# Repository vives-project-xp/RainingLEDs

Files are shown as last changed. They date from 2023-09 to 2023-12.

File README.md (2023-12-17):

# RainingLEDs
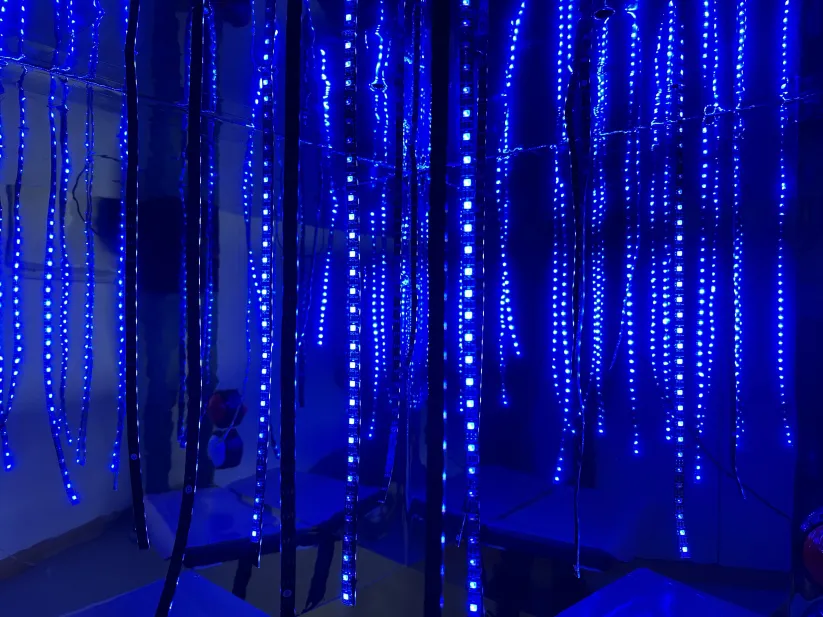
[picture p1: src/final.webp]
The box

<h1 id="What">What?</h1>
    <p>The RainingLEDs project is a project that contains a cool and unique photo location. It's made for all ages, but more focussed on influencers and social media users. Our project consists of a box with mirror foil and 17 LEDstrips, creating an infinite rain illusion. Important to know is that this project is a proof of concept that can help making a bigger version that has yet to be made (see chapter 'Project Expansion'). 
</p>
<h1 id="how">How does it work?</h1>
    <p>The 17 LEDstrips are controlled by an ESP32-C3 microcontroller. That sends signals to the strips to recreate a handful of patterns. At the side of the box the visitors can push on 2 different buttons which put the LEDs in different modes.</p>

<H1>Hardware</H1>
    The "hardware" of the project is described in this chapter.
<h2 id="require">Hardware Requirements</h2>
    <ul>
        <li>+/- 10 meters of sk6812 rgwb LEDstrips</li>
        <li>3 wooden mbf plates making a cube from 70 X 70 X 71.8 cm</li>
        <li>Mirror foil for each side</li>
        <li>ESP32-C3-DevKitM-1 microcontroller</li>
        <li>2 buttons</li>
    </ul>
</ul>
<h2>Box</h2>
    To build the box, we used MBF plates. These are strong wooden plates that can easily be drilled into. The inside of the box has the dimension 70cm x 70cm x 70cm. This is the space where someone can stand in when they want to take a picture. On the inside, we used mirror foil to create the illusion of a bigger number of LEDs. The buttons are placed at the bottom side for easy access when taking a picture. 

<h2>LEDstrips</h2>
    In the current project, we use 17 LEDstrips which are each +/- 50 cm. This is a good length for the current height of the box (70 cm), as such we didn't need an extra 5m led strip just to use 20% of it. To know if using 17 led strips works, we first tested it by using 2 data pins to control all the LEDstrips:
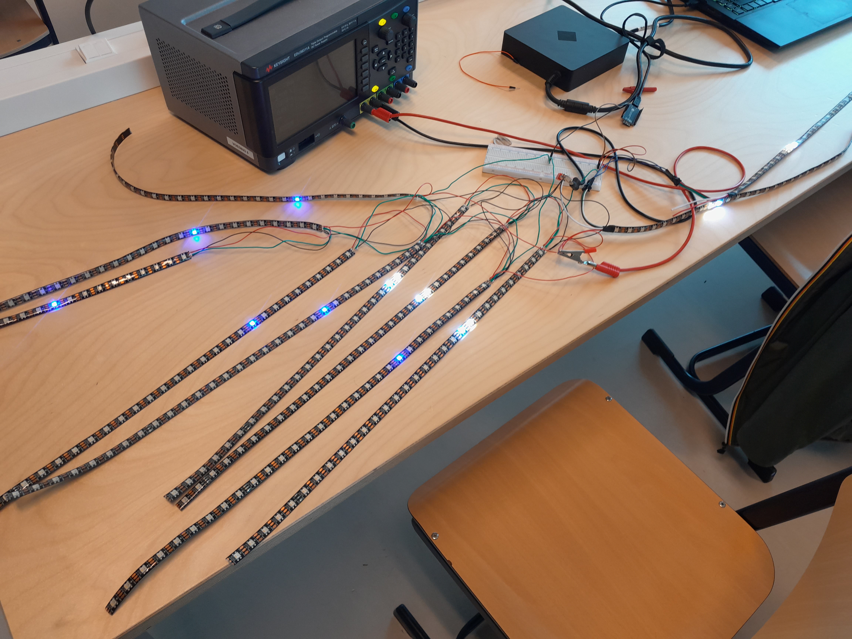
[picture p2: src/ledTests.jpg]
LED tests
    
    Since this worked, we installed the LEDs in the box and connected everything together on top. Because of the drilled holes in the top plate, installing the LEDstrips was easy. We used a breadboard to make all the connections with the esp32. This way, we could easily change the wiring if needed. Here are some things that can be improved about the lighting (additional info can be found in the 'Project Expansion' chapter):
<ul>
    <li>
        In this project, all LEDstrips hang on their own. This means that the side where LEDs are, are faced to the public or to the mirrors on the inside. They are never facing both. This is not a big problem but interferes with the illusion of the mirrors. This problem could be solved by putting 2 LEDstrips back to back, instead of hanging them alone.
    </li>
    <li>
        Each LEDstrip is connected directly to the ESP32. This means that there is maximum 3.3V on the data pin when sending a high signal. This can be the reason why the LEDs are not always working as intended. This can be solved by using a transistor or a MOSFET to amplify the signal. 
    </li>
</ul>
<h1>Software</h1>
    <h2>Adafruit_NeoPixel library</H2>
        This project was coded in C++ using the Adafruit_NeoPixel library. Follow the next steps to download the library (in Visual Studio Code).
        First you'll need to download the PlatformIO extension. Go to 'PIO Home' and select 'New Project'. Use the following settings in the next window:
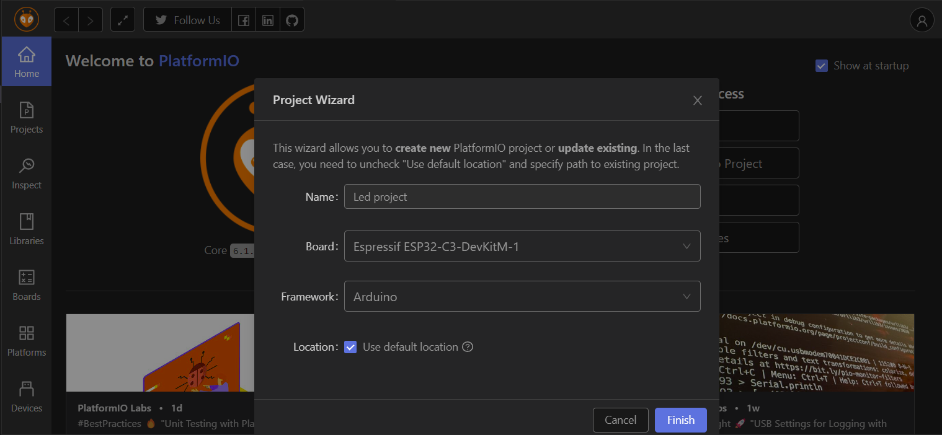
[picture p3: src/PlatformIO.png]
Platform IO screenshot
        
        Now we just need to import the Adafruit_NeoPixel.h library into our project (included inside the main.cpp file). You can simply do this by searching the Adafruit Neopixel library in the Libraries menu (at the left side in PIO Home). You should now be able to use the code on the ESP32 by building it and uploading it!
    <h2>main.cpp</h2>
        In the main program file for the project, there are 3 crucial parts:
        <ul>
            <li>
                <h3>Buttons</h3>
                The buttons are programmed to be triggered on the positive flank. This means that when the button is going from a low state to a high state, the program will interpret that as a button press. This means that nothing will happen when someone releases the button or holds it. To reduce the dander, there is a delay programmed to filter only one positive flank.
            </li>
            <li>
                <h3>Cycle</h3>
                The cycle is the part of the program that is responsible for changing the pattern. When a button is pressed, the cycle will change to the next pattern. This is done by using an array which includes all patterns where the index, which is used to filter the correct data, is increased or decreased. When the index is bigger than the array, the index will be set to 0. When the index is smaller than 0, the index will be set to the last index of the array.
            </li>
            <li>
                <h3>Sending data</h3>
                To send the data to the LEDstrips, the correct data has to be filtered. This is done by using a series of if-statements which checks the data in the array from above. when the correct data is found, the data will be sent to the ledstrips. This is done by using the Adafruit_NeoPixel library. This library has a function called 'show()' which will send the data to the LEDstrips. Since there are 4 data pins, the sent data looks like this:
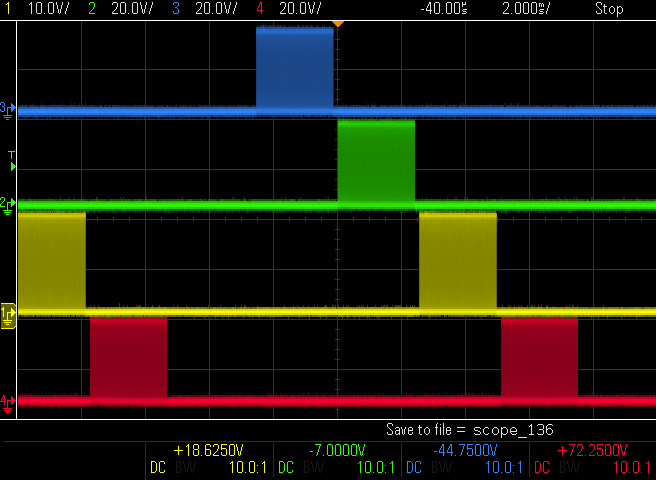
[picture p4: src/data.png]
data
                
            </li>
        </ul>
    <h2>Effects</h2>
    There are 7 different effects that can be cycled through:
    <ul>
    <li><b>Rain:</b></li> The rain effect shows rain falls from 4 LEDs in a blue color. Each datapin has a delay so the drops are falling irregular.
    <li><b>Wave fade:</b></li> The wave fade effect shows a blue wave in the LEDs.
    <li><b>Blinking star light:</b></li> This effect simulates starlight that go on and off in a white color.
    <li><b>Sunrise:</b></li> Sunset colors are slowly waving on the LEDstrips.
    <li><b>Ripple:</b></li> The LEDs are jumping up and down.
    <li><b>Fire:</b></li> A red/orange color is showed, it slightly changes which makes it looks like fire.
    <li><b>Breathing:</b></li> The LEDs are slowly changing from color in a pace that looks like breathing.
    </ul>
    <h2>MQTT</h2>
    The project also has an MQTT interaction with Project Master:  <br></br>
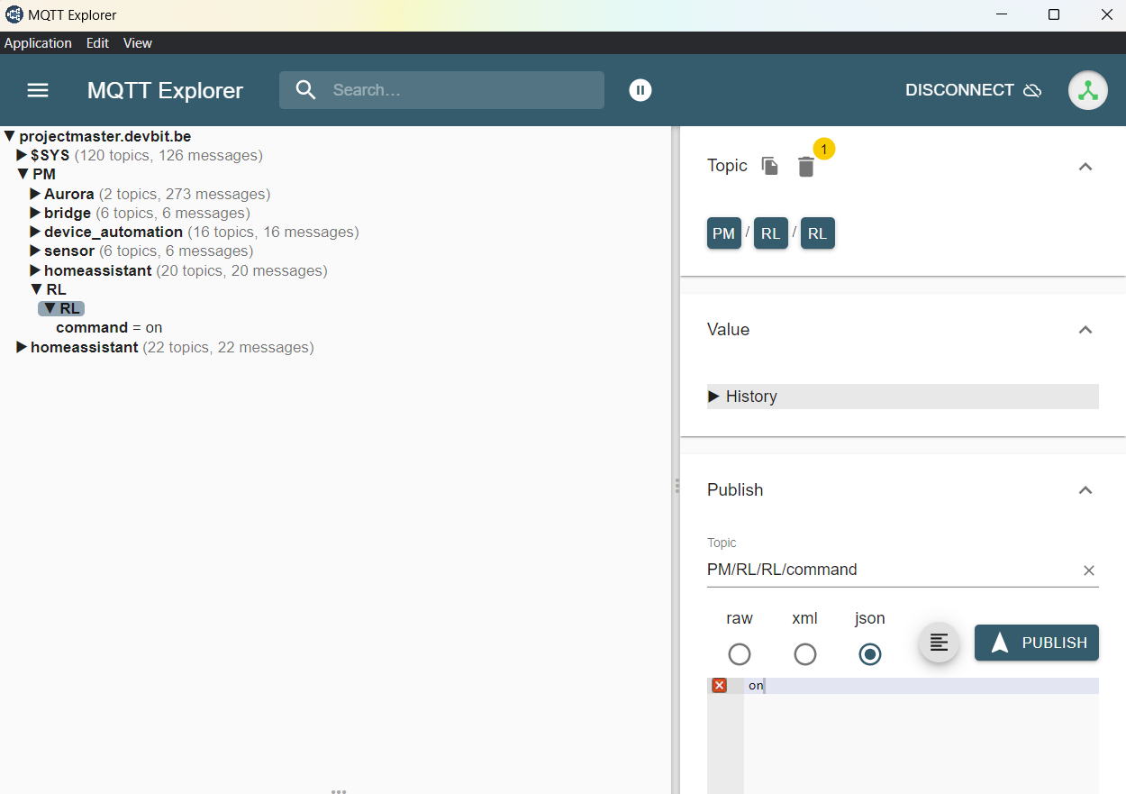
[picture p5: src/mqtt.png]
mqtt explorer
     <br></br>
    There are 4 topic that can be sent to the MQTT broker:
    <ul>
    <li>
    <b>Command:</b> </li> With the command-topic, on and off can be sent to the ESP. When sending 'ON', all LEDstrips will show the first effect. When sending 'OFF', all LEDs will go out.
    <li><b>Rgbw:</b></li> The rgbw-topic needs 4 values and will show that specific color on all LEDstrips.
    <li><b>Brightness</b></li> With the brightness command, the brightness -what a surprise- from the current effect (or color sent by MQTT) will be adjusted.
    <li><b>Effect</b></li> The effect topic shows the selected effect from 7 possible effects.
    </ul>
<h1>Project Expansion</h1>
    Because this project is a proof of concept, there was expected from us to make a project that can be expanded. This means that the project can be used as a base for a bigger project. Here are some ideas that can be used to expand it and an elaborated vision of what this could become.
    <h2>Ideas (more details below)</h2>
        <ul>
            <li>double ledstrips</li>
            <li>bigger box</li>
            <li>use of transistors for data transmission</li>
            <li>using real mirrors instead of foil</li>
            <li>bigger microcontroller</li>
            <li>PCB</li>
            <li>...</li>
        </ul>
    <h2>Our vision</h2>
    As you can see up here, there are a lot of things one can do to make this a incredible project expansion. Under here, we will explain the ideas we think are the most important to make this project a success. Here is our vision of what this project could become.
    <h3>Box</h3>
    <ul>
        <li>
            <h3>Dimensions</h3>
            Our box is in fact too small to take a picture of a full person. This makes it easy to replace, but it's also a disadvantage since the effects would be more spectacular on a human-size box. So a bigger box should be one of the primary improvements this project needs. We think it would be a good thing if a whole person could stand between the hanging ledstrips. This means that the box has to be at least 2 meters high. It would also be a good thing if the width of the box is a little bit bigger. This way, the illusion of the mirrors would be better because there could be more ledstrips and there could be place for multiple persons. <br></br>
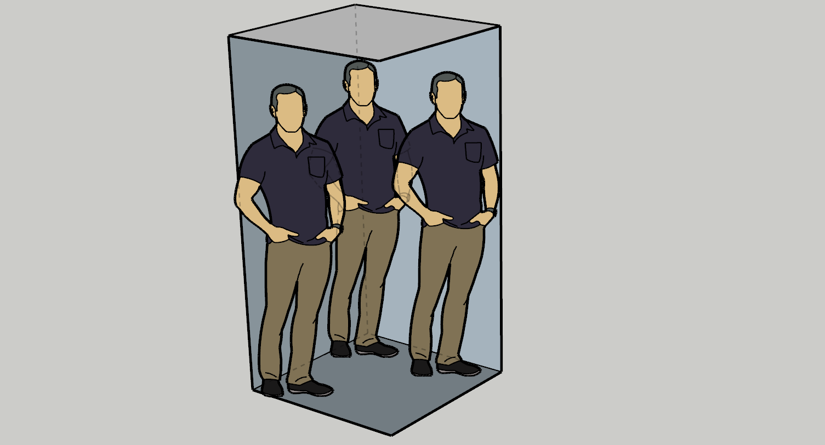
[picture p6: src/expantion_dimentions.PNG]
             <br></br>
            We think the dimensions of 100cm x 100cm x 200cm would be a good size for the box. This way, there is enough space for at least 3 people. If you want to be the project mobile, a possibility of splitting the side panels in 2 using hinges(so you create a 100 X 100 X 100 cm box) could be an option. This way, the box can be transported in a car. 
        </li>
        <li>
            <h3>Mirrors</h3>
            To create the effect that we want, the top and sides of the inside of the box has to be reflective. The best thing to use for this would be -of course- mirrors. In the prototype, we did not use real mirrors because of the expensive price. Another reason we didn't choose real mirrors is the fact that the LEDstrips have to come through the top, this would be very hard to do. Drilling holes in a mirror is a difficult process and will result in a huge money loss if it goes wrong. So for the top part, we would stick to the mirror foil. For the side parts, real mirrors could be considered. While the mirror foil is a cheap and easy way to create the wanted effect, it is not as good as a real mirror. The mirror foil is not as reflective as a real mirror, so the effect is less spectacular.
        </li>
    </ul>
    <h3>LEDstrips</h3>
        When the box becomes bigger, it is normal that the number and length of the ledstrips will increase too. If we want to make a box as described above, a number of 25 ledstrips hanging from above would be perfect in our vision. Since we wanted to double the LEDstrips for the mirror effect (see chapter Hardware), this would come down to 50 ledstrips. When we make each of them 150 cm long, that would mean that there would be 75 meters of ledstrips. This would come down to 277 euro with the type of LEDs we are currently using.
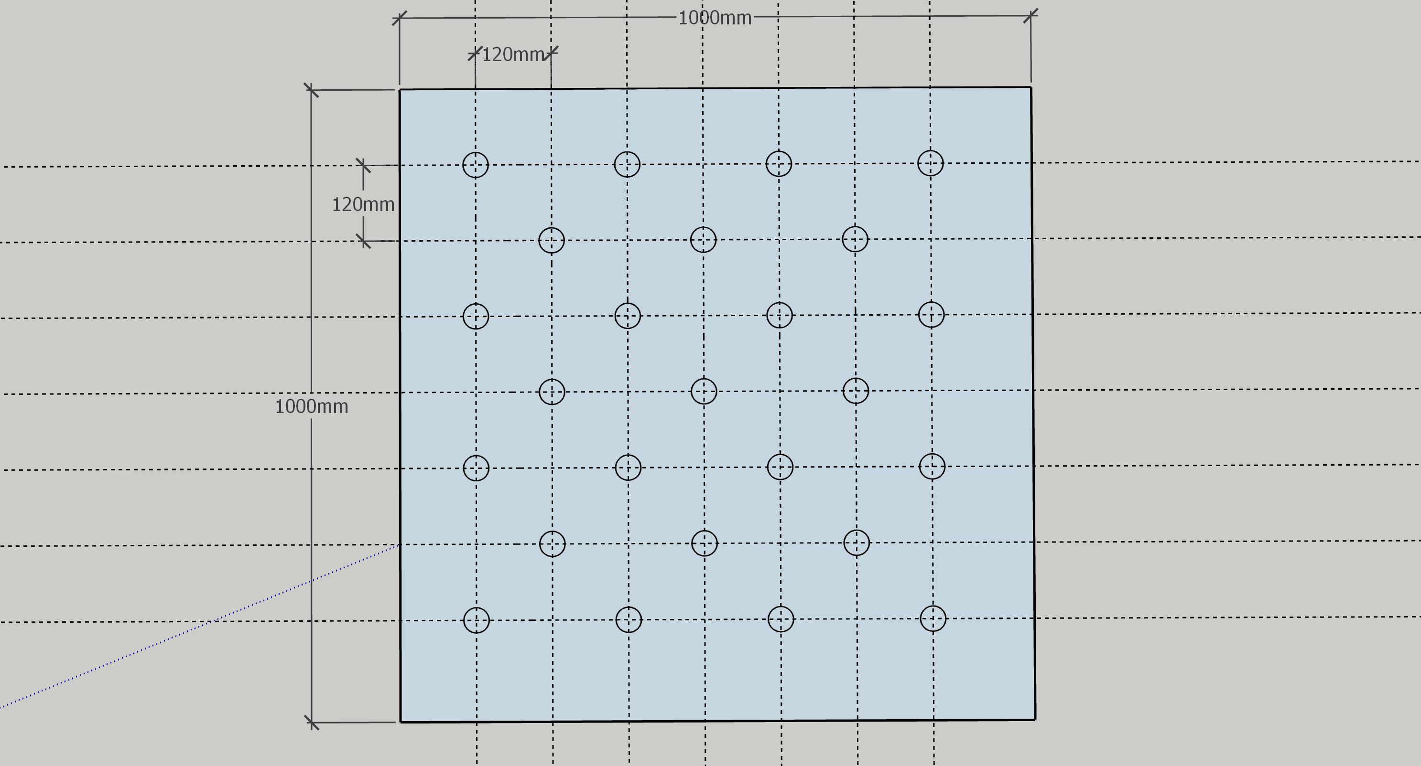
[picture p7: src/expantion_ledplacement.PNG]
        
        This would be a good placement of the LEDstrips. With the staggered placement, the mirrors will reflect as much of the light as possible resulting in a beautiful photo.
    <h3>Electronics</h3>
    <ul>
        <li>
            <h3>Microcontroller</h3>
                The best way to control all ledstrips is when every LEDstrip has its own data pin. This way it is possible for every LEDstrip to do something completely different, which would result in no boundaries for patterns. In the current project, we used an ESP32-C3-DevKitC-02.
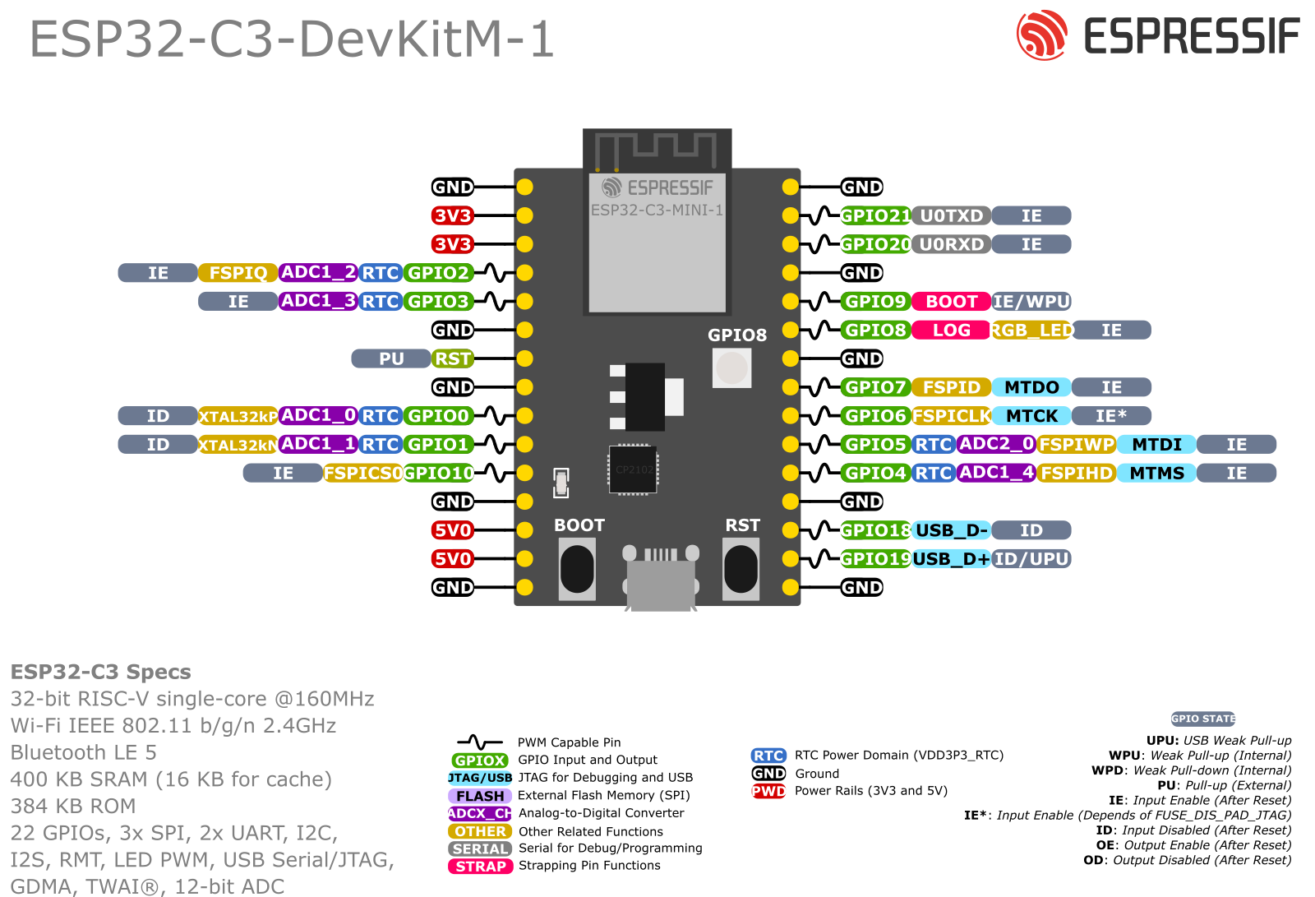
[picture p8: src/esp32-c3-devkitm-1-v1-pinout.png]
esp32-c3-devkitm-1-v1-pinout
                
                This microcontroler has 15 GPIO ports. this is enough for the prototype but not for an expanded version with 25 double LEDstrips. And if we want to keep the two cycle buttons, we would need 27. A good solution would be the ESP32-WROOM-32. This microcontroler has 38 GPIO ports. This would be enough for the expanded version and would give us the possibility to add more buttons or other components.
                <br></br>
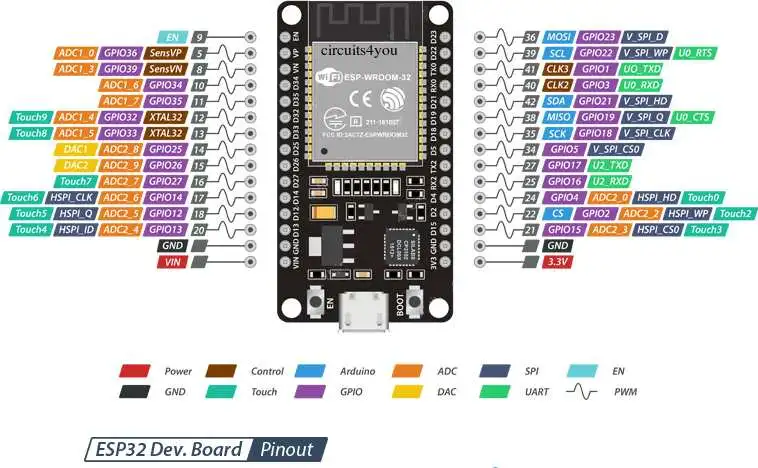
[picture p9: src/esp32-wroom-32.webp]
esp32-wroom
                
        </li>
        <li>
            <h3>Powersupply</h3>
                With 50 ledstrips, the power consumption will of course be a lot higher. This means that the power supply has to be more powerful. When we use 50 ledstrips, the max power consumption would be around 30 Watt. The project would have to be connected to a 5V 6A power supply like the LHA30F-5-SNY: <br></br>
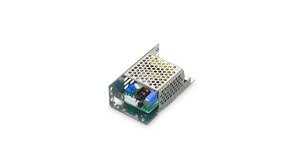
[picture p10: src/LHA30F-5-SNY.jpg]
LHA30F-5-SNY
                
        </li>
        <li>
            <h3>PCB</h3>
        </li>
        To connect all LEDstrips, buttons and other components to the microcontroller, a PCB can be made. In our case, we placed a breadboard on top of the box that connects all components, which makes it easier to see what all our connections and components are when the project will be expanded.
        <li>
            <h3>Data transmission</h3>
        </li>
        To make sure the data transmission from the microcontroller to the LEDstrips goes well, transistors could be used. Since in our case the ESP needs 3.3V and the LEDs 5V, data conflicts could be possible. We sometimes experienced this in the from of LEDs showing colors that weren't meant to be showed or flickering LEDs when adjusting the brightness. But since we could fix most of them in the software, we didn't implement transistors in our case. Another option is to use a logic level converter between the ESP32 and LEDs: 
        <br></br>
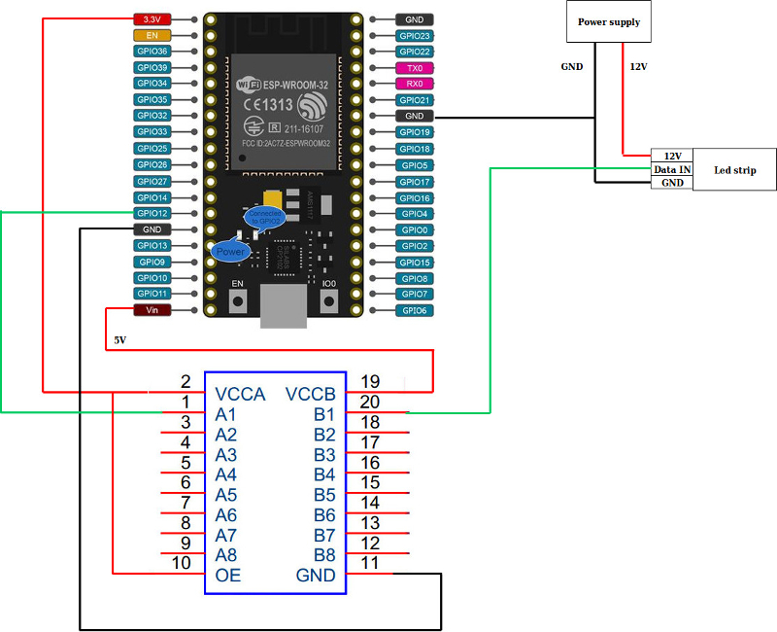
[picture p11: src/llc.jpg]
logic level converter
        
    </ul>

<h1 id="troubleshooting">Troubleshooting & problems</h1>
<h2>LEDstrips</h2>
We had to re-solder a few LEDstrips because the cables were detached while we were putting them in the box. When all the LEDs were in place we noticed that 2 strips stopped functioning and replaced them by 2 smaller strips.
<h2>Coding</h2>
We started coding some simple functions to test the LEDs. After that we extended the LEDstrip to see if it would still work with the ESP32. We encountered a problem with some code examples where the LEDs would not follow the code and would simply show random colours. When the voltage was adapted to the right value, it started working again with a larger LEDstrip. This was all done with one data line, however we wanted to use mutiple data lines to create a more natural flow between the LEDstrips so that there would be some variation. This worked with four data lines but only one pattern at a time. We still had some problems with cycling between dynamic patterns with multiple data lines.
<h2>Power supply</h2>
We began with following the datasheet, so we used a voltage of 3.6 with a school power supply. Because we were working with a voltage of 3.6 we had to consider to limit our brightness so we wouldn't take up a whole lot of wattage. We concluded that the ideal brightness for the LEDs was 60%. This also made sure that the functions worked properly. When we rearranged the wiring of our project, we made it work using our own power supply with 5V.
<h2>Buttons</h2>
The buttons were implemented fairly quickly, but we ran into some problems: they only worked with static functions, not with dynamic patterns and a delay occurred when pushed. We solved the delay problem by adding a debounce system that ensured that only one button press is registered. By working with threads we managed to cycle between dynamic functions.
<h1 id="image">Additional Images</h1>
<h2>Electric schematic</h2> 
First, we wanted to make a LEDcube using 2 data pins and 2 buttons. Because of the 2 data pins, we could send 2 different patterns to the LEDstrips which could make the illusion of falling rain or other dynamic patterns. The initial electric schematic looked like this:
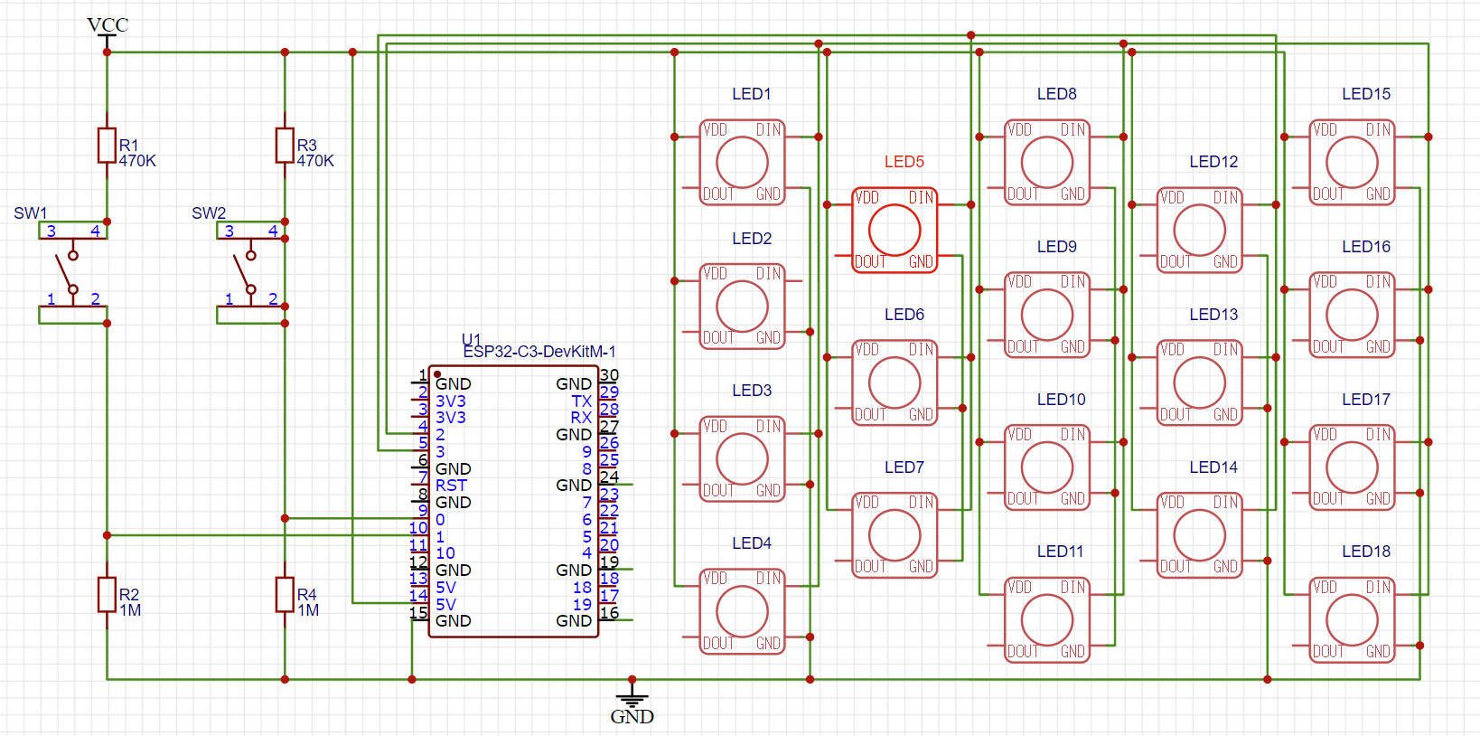
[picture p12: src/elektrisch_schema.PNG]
elektrisch schema

When we slowly progressed on the project, we noticed that the difference between 2 and 4 data pins was not that big. With 4 data pins, there is a grated variety and freedom in the patterns we can create. There are still 2 buttons to cycle between the patterns. The final electrical schematic looks like this:
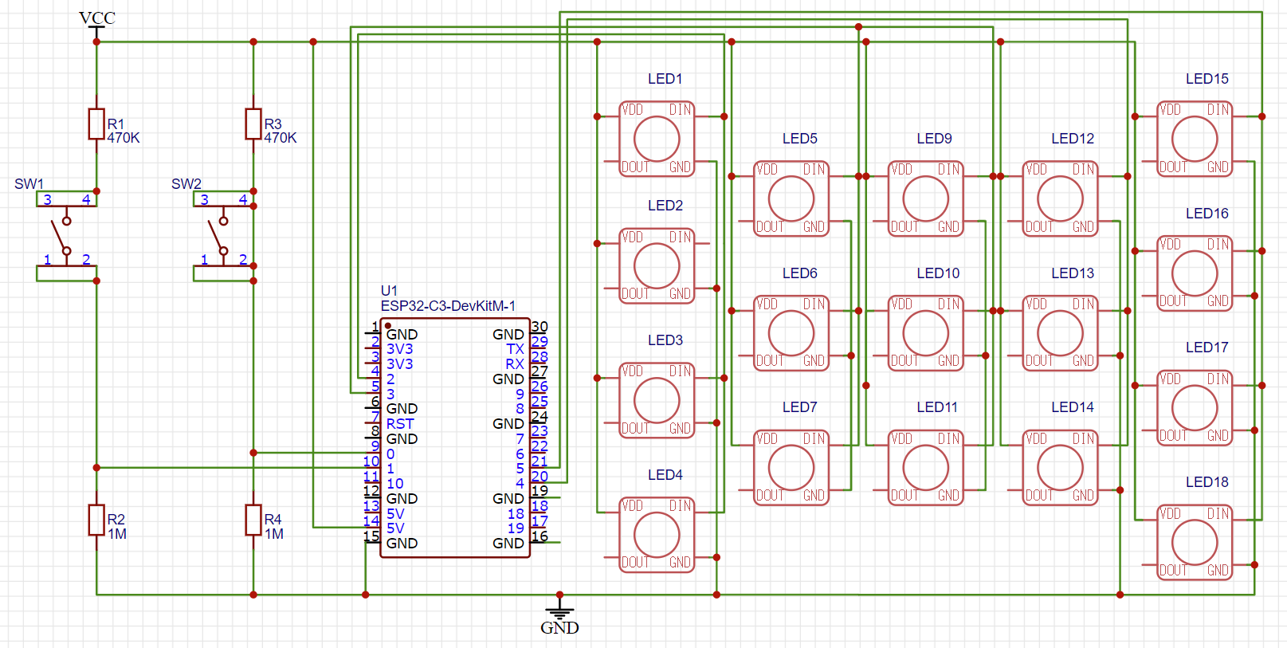
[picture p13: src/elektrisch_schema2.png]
elektrisch schema2

<figcaption>The Electric schematic shows into detail how all the LEDs are connected to the ESP32 microcontroller.</figcaption>
<h2>Projectcanvas</h2>
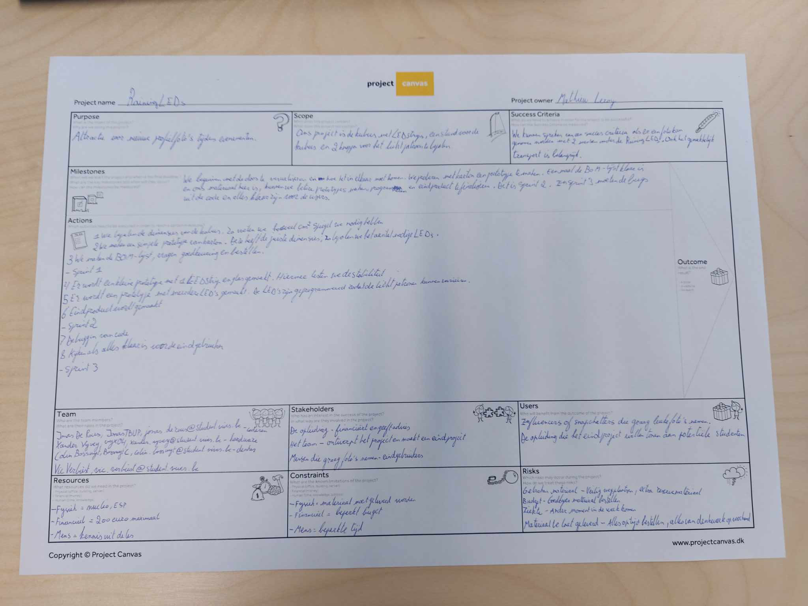
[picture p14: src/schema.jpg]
Projectcanvas

<figcaption>The projectcanvas shows the different aspects of the project. It was the first plan of the project and contains things like the tasks that needed to be done and the stakeholders.</figcaption>
<h2>Prototype 1</h2>
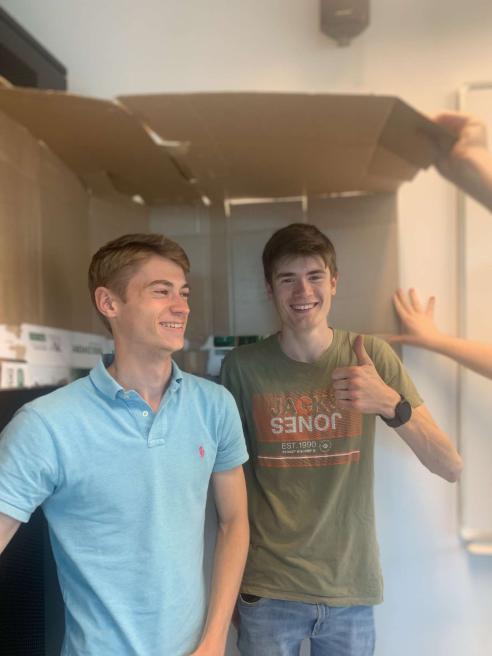
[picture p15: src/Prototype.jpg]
Prototype 1

<figcaption>This is the first, very simply, prototype. The main goal was to see how big the box has to be and how many LEDs we need.</figcaption>
<h1 id="members">Team members</h1>
<p>This project was developed by VIVES students Jonas De Rous, Xander Vyvey, Colin Bossuyt and Vic Verbiest in 2023.
<br></br>
More questions? You can contact us here: xander.vyvey@student.vives.be</p>

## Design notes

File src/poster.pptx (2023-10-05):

RainingLEDs

Project Experience

Een selfie-kubus die gebruik maakt van LEDs en spiegels om de illusie van "infinite LEDs" te creëren, wat gebruikt kan worden als leuke fotostand.

18 ledstrips zorgen voor een ‘RainingLEDs’ effect, door het gebruik van 3 houten wanden en aangebrachte spiegels wordt deze oneindige illusie extra versterkt.

Voor de aansturing van de LEDs werd een ISP32, waarbij zowel hardware- als softwarekennis nodig waren.

P

Professionele bachelor
Elektronica-ICT

- Software Engineering
- Hardware Engineering
- Network- & System administration
- Artificial Intelligence
- Personal development

Instructies:
1. Pas de project titel aan en voeg een subtitel toe
2. Schrijf eronder een korte omschrijving van de probleemstelling, jullie uitwerking, de gebruikte componenten en welke leerstof jullie nodig hadden.
3. Vervang de 3 foto’s door mooie foto’s van jullie product/prototype.
4. Noteer jullie namen bij het team
5. Indien een leerlijn niet werd gebruikt in jullie project, vervang het vinkje dan door een leeg vierkantje.
6. Vervang de QR code door eentje die verwijst naar jullie GitHub repository.

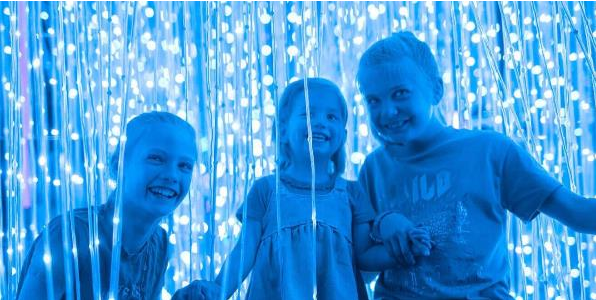
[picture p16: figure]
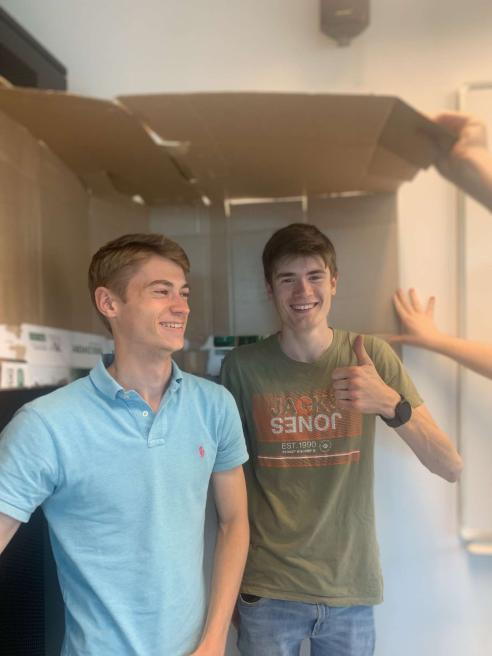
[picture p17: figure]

Team
- Colin Bossuyt, 2e jaar Software Engineering
- Vic Verbiest, 2e jaar Software Engineering
- Jonas De Rous, 3e jaar Software Engineering and AI
- Xander Vyvey, 2e jaar Network- & System admin

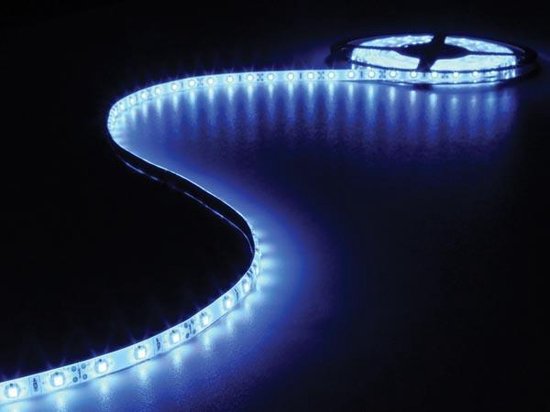
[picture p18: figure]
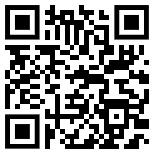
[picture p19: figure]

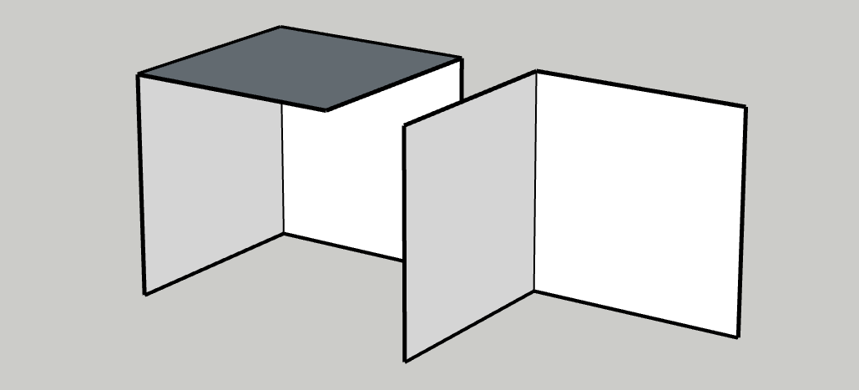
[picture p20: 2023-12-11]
src/expantion_split_box.PNG

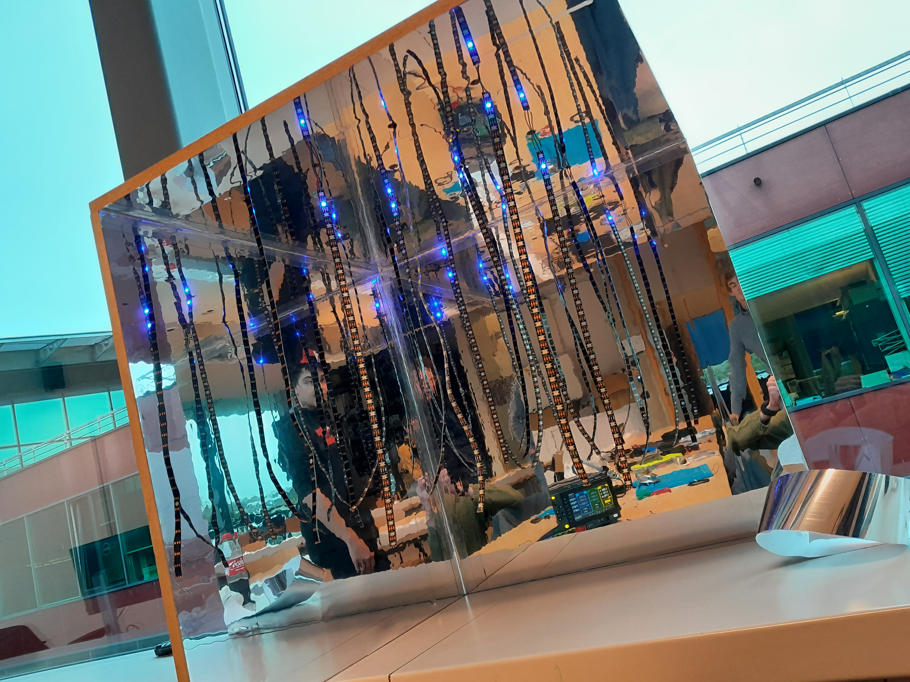
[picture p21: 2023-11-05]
src/box.jpg

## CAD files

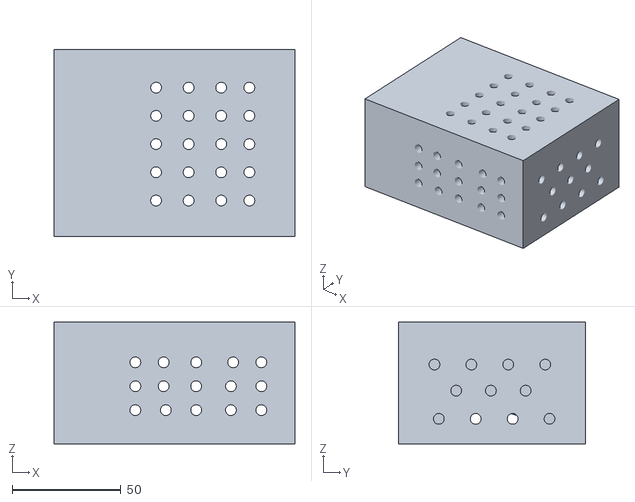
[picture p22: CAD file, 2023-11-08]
3D Prints/voeding 3D print v2.stl
111.0 x 86.0 x 56.0

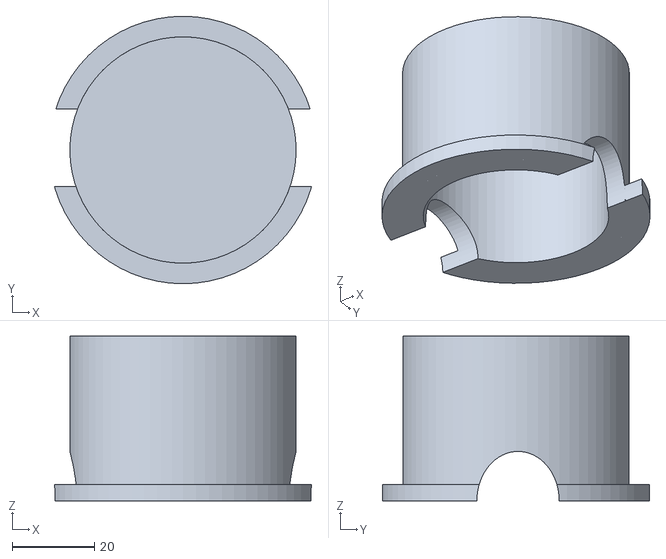
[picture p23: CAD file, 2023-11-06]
3D Prints/Button Box v2.stl
62.5 x 65.0 x 40.0

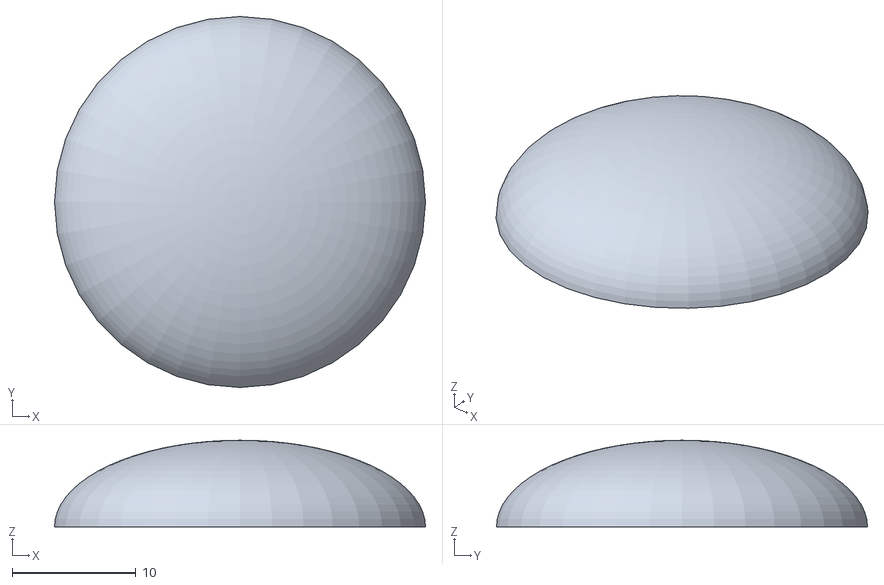
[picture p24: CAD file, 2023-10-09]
3D Prints/Button.stl
30.0 x 30.0 x 7.00

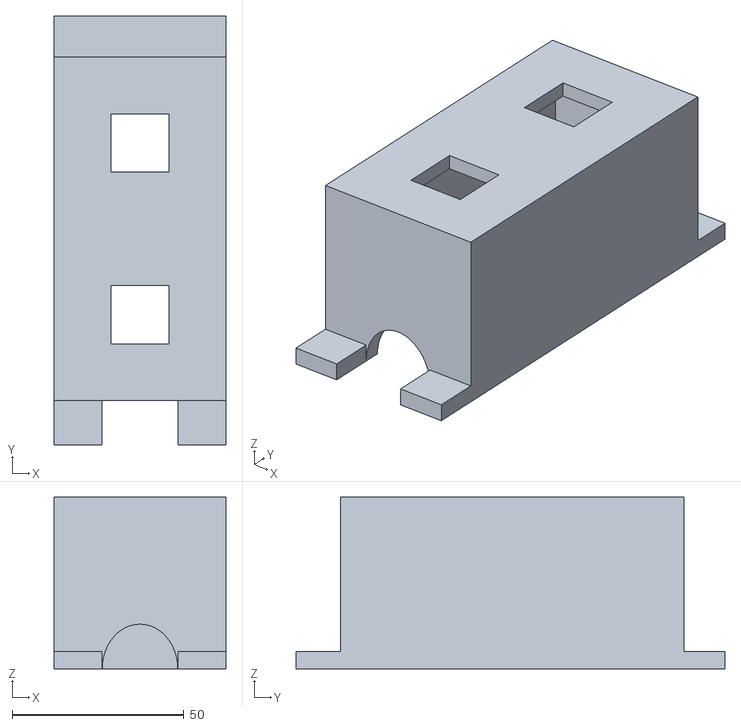
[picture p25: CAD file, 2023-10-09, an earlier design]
3D Prints/Button Box.stl
50.0 x 125.0 x 50.0

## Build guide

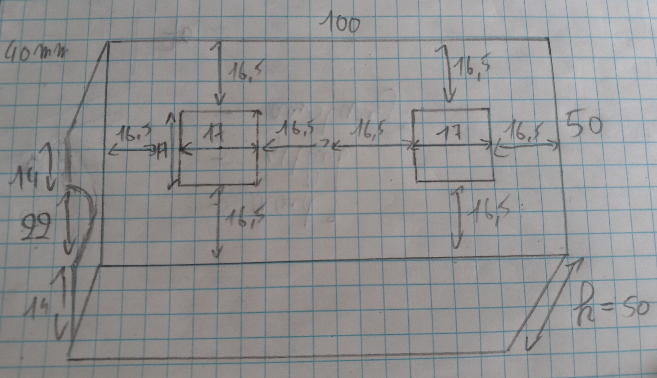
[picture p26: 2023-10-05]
3D Prints/3D_print_ontwerp1.jpg

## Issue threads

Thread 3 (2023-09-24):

Visualisation box

JonasTBUP, 2023-09-24:
A clear visualisation of the box for our project. The dimensions, the material, the stability and the mobility is an important thing to be able to make our box.

Closed 2023-10-02.

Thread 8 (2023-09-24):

Sprint 1 eindmeeting

JonasTBUP, 2023-09-24:
Every issue that should be finished by Sprint 1. These include:
- Visualisation box
- Bill of Material
- Prototype 1
- Readme invullen
- Affice concept

Closed 2023-10-02.

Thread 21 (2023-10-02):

Krimpfolie rond LED's

JonasTBUP, 2023-10-02:
De krimpfolie rond de LED's doen zodat het stevig wordt.

vyx04, 2023-11-27:
Uiteindelijk zullen we dit niet doorvoeren, omdat het weinig invloed heeft bij onze toepassing. Dit hebben we ondervonden na het uitproberen ervan op 1 LEDstrip.

Closed 2023-11-27.

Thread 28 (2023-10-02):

Looking for driver solution

vyx04, 2023-10-02:
Looking for a solution to the current problem we experience with the LEDs and ISP, the LED current is too high for the ISP to handle so we need to look for a driver.

Closed 2023-10-09.

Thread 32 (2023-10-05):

Designing 3D button box

vyx04, 2023-10-05:
Design of the 3D print to know the dimensions and size. The print will feature as the button box, where the 2 buttons will be attached to.

Closed 2023-10-05.

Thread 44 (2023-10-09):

Houten platen aftekenen

vyx04, 2023-10-09:
Het correct aftekenen en afmeten van de gewenste afmetingen op de grote houten mdf plaat.

Closed 2023-10-09.

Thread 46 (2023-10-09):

LEDs knippen

Vic-Verbiest, 2023-10-09:
LEDs knippen op de correcte lengte van 0.5 meter

Closed 2023-10-09.

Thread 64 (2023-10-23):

Oplossen probleem van haperende LEDstrips

vyx04, 2023-10-23:
Het opslossen van een probleem wanneer meerdere LEDstrips aangesloten worden op de ESP32, wanneer dit gedaan werd haperden de LEDstrips en verliep het patroon niet meer in een vloeiende beweging. De oplossing bleek een minder hoog voltage toelaten voldoende te zijn.

Closed 2023-10-23.

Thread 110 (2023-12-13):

Bug fix: rain effect

vyx04, 2023-12-13:
Het fixen van een bug in de rainEffect functie waarbij slechts 1 druppel tegelijk te zien was op de LED-strip.

Closed 2023-12-13.

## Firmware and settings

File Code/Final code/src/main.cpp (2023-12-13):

#include <Arduino.h>
#include <Adafruit_NeoPixel.h>

#include <PubSubClient.h>
#include <WiFi.h>

#include <ArduinoJson.h>

#include <freertos/FreeRTOS.h>
#include <freertos/task.h>

#include "effects.h"
#include "info.h"

const char* mqtt_rgbw ="PM/RL/RL/rgbw";
const char* mqtt_command ="PM/RL/RL/command";
const char* mqtt_effect ="PM/RL/RL/effect";
const char* mqtt_brightness ="PM/RL/RL/brightness";

const int mqtt_port = 1883;

WiFiClient espClient;
PubSubClient client(espClient);

#define PIN_LEDSTRIP1 2
#define PIN_LEDSTRIP2 3
#define PIN_LEDSTRIP3 4
#define PIN_LEDSTRIP4 5
#define PIN_BUTTON_WHITE 1
#define PIN_BUTTON_RED 0

const int MIN_BRIGHTNESS = 10;
const int MAX_BRIGHTNESS = 60;
const int NUMPIXELS = 60;
const int DEBOUNCE_DELAY = 50;

Adafruit_NeoPixel ledstrip1 = Adafruit_NeoPixel(NUMPIXELS, PIN_LEDSTRIP1, NEO_GRBW + NEO_KHZ800);
Adafruit_NeoPixel ledstrip2 = Adafruit_NeoPixel(NUMPIXELS, PIN_LEDSTRIP2, NEO_GRBW + NEO_KHZ800);
Adafruit_NeoPixel ledstrip3 = Adafruit_NeoPixel(NUMPIXELS, PIN_LEDSTRIP3, NEO_GRBW + NEO_KHZ800);
Adafruit_NeoPixel ledstrip4 = Adafruit_NeoPixel(NUMPIXELS, PIN_LEDSTRIP4, NEO_GRBW + NEO_KHZ800);

Adafruit_NeoPixel LEDSTRIPS[] = {ledstrip1, ledstrip2, ledstrip3, ledstrip4};
int NUM_LEDSTRIPS = 4;

int cycle = 0;
String currentEffect = EFFECTS[0];
String previousEffect = EFFECTS[0];
int delayTime = 0;
bool redButtonState = false;
bool redButtonPreviousState = false;
bool whiteButtonState = false;
bool whiteButtonPreviousState = false;

bool mqttCommandReceived = false;
String mqttCommand;

int receivedR = -1;
int receivedG = -1;
int receivedB = -1;
int receivedW = -1;

bool effectRunning = false;

const Color fillColor = {0, 255, 0, 0};
const int dropAmount = 31; 
const int dropLength = 3; 
const String waveColor = "blue"; 

int drops[dropAmount] = {0};

long hue = 0;


int GetEffectIndex(String effect);
void SwitchToNextEffect();
void SwitchToPreviousEffect();

TaskHandle_t redButtonTask, whiteButtonTask;

void redButtonThread(void *pvParameters) {
  while (1) {
    bool currentState = digitalRead(PIN_BUTTON_RED);
    vTaskDelay(10 / portTICK_PERIOD_MS);

    if (currentState != redButtonState) {
      redButtonState = currentState;
      if (currentState == HIGH) {
        SwitchToNextEffect();
      }
    }
  }
}

void whiteButtonThread(void *pvParameters) {
  while (1) {
    bool currentState = digitalRead(PIN_BUTTON_WHITE);
    vTaskDelay(10 / portTICK_PERIOD_MS); 

    if (currentState != whiteButtonState) {
      whiteButtonState = currentState;
      if (currentState == HIGH) {
        SwitchToPreviousEffect();
      }
    }
  }
}


void callback(char *topic, byte *payload, unsigned int length) {
  String messageTemp;
  
  for (int i = 0; i < length; i++) {
    messageTemp += (char)payload[i];
  }

  Serial.print("Received message on topic: ");
  Serial.println(topic);
  Serial.print("Message: ");
  Serial.println(messageTemp);

  // If the message is a command for the LEDs
  if (String(topic) == mqtt_command) {
    mqttCommandReceived = true;
    mqttCommand = messageTemp;
  }
   else if (String(topic) == mqtt_brightness) {
    int brightness = messageTemp.toInt();
    if (brightness >= 0 && brightness <= 255) {
      for (int i = 0; i < NUM_LEDSTRIPS; i++) {
        LEDSTRIPS[i].setBrightness(brightness);
        LEDSTRIPS[i].show();
      }
    }
  }
  // If the message is on the RGBW topic
  else if (String(topic) == mqtt_rgbw) {
    // Parse the message as an RGBW color
    sscanf(messageTemp.c_str(), "%d,%d,%d,%d", &receivedR, &receivedG, &receivedB, &receivedW);
    effectRunning = false;
  }
  else  if (String(topic) == mqtt_effect) {
    if (messageTemp == "waveFade" || messageTemp == "rainEffect" || messageTemp == "sunriseEffect" || messageTemp == "rippleEffect" || messageTemp == "blinkingStarlight" || messageTemp == "fire" || messageTemp == "breathingEffect") {
      currentEffect = messageTemp;
      effectRunning = true;
      Serial.println("Current effect: " + currentEffect); 
    }
  }
  
}

void setup() {
  pinMode(PIN_BUTTON_RED, INPUT);
  pinMode(PIN_BUTTON_WHITE, INPUT);

  xTaskCreate(redButtonThread, "RedButtonTask", 1000, NULL, 1, &redButtonTask);
  xTaskCreate(whiteButtonThread, "WhiteButtonTask", 1000, NULL, 1, &whiteButtonTask);
  ledstrip1.begin();
  ledstrip2.begin();
  ledstrip3.begin();
  ledstrip4.begin();
  ledstrip1.setBrightness(30);
  ledstrip2.setBrightness(30);
  ledstrip3.setBrightness(30);
  ledstrip4.setBrightness(30);
  fillAll(LEDSTRIPS, NUM_LEDSTRIPS, {0, 0, 0, 0});
  ledstrip1.show();
  ledstrip2.show();
  ledstrip3.show();
  ledstrip4.show();

  currentEffect = EFFECTS[0];
  effectRunning = true;

  Serial.begin(115200);

  // Connect to WiFi
  WiFi.begin(ssid, password);
  while (WiFi.status() != WL_CONNECTED) {
  delay(1000);
  Serial.println("Connecting to WiFi..");
  }
  Serial.println("Connected to the WiFi network");

  // Set MQTT server and callback function
  client.setServer(mqtt_server, mqtt_port);
  client.setCallback(callback);

  // Subscribe to the MQTT topic
  client.subscribe(mqtt_rgbw);
  client.subscribe(mqtt_effect);
  client.subscribe(mqtt_command);
  client.subscribe(mqtt_brightness);
}

void reconnect() {
  // Loop until reconnected
  while (!client.connected()) {
    Serial.println("Attempting MQTT connection...");

    // Attempt to connect
    if (client.connect("RL", mqtt_user, mqtt_password)) {
      Serial.println("Connected to MQTT broker");

      // Subscribe to the MQTT topic after reconnection
      client.subscribe(mqtt_rgbw);
      client.subscribe(mqtt_effect);
      client.subscribe(mqtt_command); 
      client.subscribe(mqtt_brightness);
    } else {
      Serial.print("Failed, rc=");
      Serial.print(client.state());
      Serial.println(" Retry in 5 seconds");
      // Wait 5 seconds before retrying
      delay(5000);
    }
  }
}

void loop() {
  
  // Reconnect to MQTT broker if necessary
  if (!client.connected()) {
    reconnect();
  }
  client.loop();

   if(mqttCommandReceived){
    if (mqttCommand == "ON") {
       Serial.println("Received MQTT command: ON");
      // Start the first effect
      currentEffect = "rainEffect";
      previousEffect = "";
    } else if (mqttCommand == "OFF") {
      Serial.println("Received MQTT command: OFF");
      // Turn off the LEDs
      fillAll(LEDSTRIPS, NUM_LEDSTRIPS, {0, 0, 0, 0});
      ledstrip1.show();
      ledstrip2.show();
      ledstrip3.show();
      ledstrip4.show();
      currentEffect = "";
  }
    mqttCommandReceived = false;
    } else if (receivedR != -1 && receivedG != -1 && receivedB != -1 && receivedW != -1) {
  // Create a Color object from the received RGBW values
  Color receivedColor = {receivedR, receivedG, receivedB, receivedW};
  // Set all LEDs to the received color
  fillAll(LEDSTRIPS, NUM_LEDSTRIPS, receivedColor);
  ledstrip1.show();
  ledstrip2.show();
  ledstrip3.show();
  ledstrip4.show();

  // Reset the received RGBW values
  receivedR = -1;
  receivedG = -1;
  receivedB = -1;
  receivedW = -1;
  currentEffect = "";
}
else if (effectRunning){
  if (currentEffect == "rainEffect") {
    
    if (currentEffect != previousEffect) {
      delayTime = Delays::rainEffect;
      previousEffect = currentEffect;
    }
    rainEffects(LEDSTRIPS, NUM_LEDSTRIPS);
  }
  else if (currentEffect == "waveFade") {
    if (currentEffect != previousEffect) {
      delayTime = Delays::waveFade;
    }
    waveFadeEffect(LEDSTRIPS, NUM_LEDSTRIPS, waveColor);
  }
  else if (currentEffect == "blinkingStarlight") {
    if (currentEffect != previousEffect) {
      delayTime = Delays::blinkingStarlight;
    }
    blinkingStarlights(LEDSTRIPS, 200);
  }
  else if (currentEffect == "sunriseEffect") { 
    if (currentEffect != previousEffect) {
      delayTime = Delays::sunrise;
    }
    sunriseEffect(LEDSTRIPS, NUM_LEDSTRIPS);
  }
  else if (currentEffect == "rippleEffect") {  
    if (currentEffect != previousEffect) {
      delayTime = Delays::rippleEffect;
    }
    rippleEffects(LEDSTRIPS, NUM_LEDSTRIPS, {152, 255, 152, 100});
  }
  else if (currentEffect == "fire"){
   if (currentEffect != previousEffect) {
      delayTime = Delays::other;
    }
    fireEffect(LEDSTRIPS, NUM_LEDSTRIPS);
  }
  else if (currentEffect == "breathingEffect"){
    if (currentEffect != previousEffect) {
      delayTime = Delays::other;
    }
    breathingEffect(LEDSTRIPS, NUM_LEDSTRIPS);
  }
  else {
    fillAll(LEDSTRIPS, NUM_LEDSTRIPS, {0,0,0,0});
    delayTime = 0;
  }
  for (int i = 0; i < NUM_LEDSTRIPS; i++) {
    LEDSTRIPS[i].show();
  }
}
}


int GetEffectIndex(String effect) {
  int numEffects = sizeof(EFFECTS) / sizeof(EFFECTS[0]);
  for (int i = 0; i < numEffects; i++) {
    if (EFFECTS[i] == effect) {
      return i;
    }
  }
  return -1;
}

void SwitchToNextEffect() {
  int numEffects = sizeof(EFFECTS) / sizeof(EFFECTS[0]);
  int index = GetEffectIndex(currentEffect);
  if (index == -1 || index == numEffects - 1) {
    currentEffect = EFFECTS[0];
  } else {
    currentEffect = EFFECTS[index + 1];
  }
}

void SwitchToPreviousEffect() {
  int numEffects = sizeof(EFFECTS) / sizeof(EFFECTS[0]);
  int index = GetEffectIndex(currentEffect);
  if (index == -1 || index == 0) {
    currentEffect = EFFECTS[numEffects - 1];
  } else {
    currentEffect = EFFECTS[index - 1];
  }
}

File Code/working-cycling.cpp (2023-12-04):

#include <Adafruit_NeoPixel.h>

#define PIN            2
#define PIN2           3
#define PIN3           4
#define PIN4           5
#define NUMPIXELS      31
#define BUTTON         1
#define BUTTON2        0
#define NUM_DROPS      31
#define TESTPIN        6
#define BRIGHTNESS_MIN 10
#define BRIGHTNESS_MAX 100
#define DEBOUNCE_DELAY 50
#define NUM_MODES 4

Adafruit_NeoPixel strip = Adafruit_NeoPixel(NUMPIXELS, PIN, NEO_GRBW + NEO_KHZ800);
Adafruit_NeoPixel strip2 = Adafruit_NeoPixel(NUMPIXELS, PIN2, NEO_GRBW + NEO_KHZ800);
Adafruit_NeoPixel strip3 = Adafruit_NeoPixel(NUMPIXELS, PIN3, NEO_GRBW + NEO_KHZ800);
Adafruit_NeoPixel strip4 = Adafruit_NeoPixel(NUMPIXELS, PIN4, NEO_GRBW + NEO_KHZ800);
Adafruit_NeoPixel teststrip = Adafruit_NeoPixel(NUMPIXELS, TESTPIN, NEO_GRBW + NEO_KHZ800);


boolean oldState = HIGH;
boolean oldState2 = HIGH;
int mode = 0;
int current_mode = 0;

void colorWipe(uint32_t color, int wait) {
  for(int i=0; i<strip.numPixels(); i++) {
    strip.setPixelColor(i, color);
    strip2.setPixelColor(i, color);
    strip3.setPixelColor(i, color);
    strip4.setPixelColor(i, color);
    teststrip.setPixelColor(i, color);  
    strip.show();
    strip2.show();
    strip3.show();
    strip4.show();
    teststrip.show();
    delay(wait);
  }
}

void rainEffect() {
  int drops[NUM_DROPS] = {0};

  // Initialize drop positions
  for (int i = 0; i < NUM_DROPS; i++) {
    drops[i] = i * (strip.numPixels() / NUM_DROPS);
  }
  while (true) {
    // For each drop...
    for (int i = 0; i < NUM_DROPS; i++) {
      // Turn off the current drop
      strip.setPixelColor(drops[i], strip.Color(0, 0, 0));
      strip2.setPixelColor(drops[i], strip2.Color(0, 0, 0));
      strip3.setPixelColor(drops[i], strip3.Color(0, 0, 0));
      strip4.setPixelColor(drops[i], strip4.Color(0, 0, 0));

      // Generate a new position for the drop
      drops[i] = random(strip.numPixels() - 3);

      // Turn on the new drop
      strip.setPixelColor(drops[i], strip.Color(255, 255, 255));
      strip2.setPixelColor(drops[i], strip2.Color(255, 255, 255));
      strip3.setPixelColor(drops[i], strip3.Color(255, 255, 255));
      strip4.setPixelColor(drops[i], strip4.Color(255, 255, 255));
    }

    strip.show();
    strip2.show();
    strip3.show();
    strip4.show();
    delay(200);  
  }
}

// void rainEffect() {
//   int drops[NUM_DROPS] = {0};

//   // Initialize drop positions
//   for (int i = 0; i < NUM_DROPS; i++) {
//     drops[i] = i * (strip.numPixels() / NUM_DROPS);
//   }
//   while (true) {
//     // For each drop...
//     for (int i = 0; i < NUM_DROPS; i++) {
//       // Turn off the current drop
//       strip.setPixelColor(drops[i], strip.Color(0, 0, 0));
//       strip.setPixelColor(drops[i] + 1, strip.Color(0, 0, 0));
//       strip.setPixelColor(drops[i] + 2, strip.Color(0, 0, 0));

//       // Generate a new position for the drop
//       drops[i] = random(strip.numPixels() - 3);

//       // Turn on the new drop
//       strip.setPixelColor(drops[i], strip.Color(0, 0, 255));
//       strip.setPixelColor(drops[i] + 1, strip.Color(0, 0, 255));
//       strip.setPixelColor(drops[i] + 2, strip.Color(0, 0, 255));
//     }

//     strip.show();
//     delay(500);
// }
// }

void blueWaveSignal(int delayTime) {
  int blueIntensity[strip.numPixels()];

  while (true) {
    for (int i = 0; i < strip.numPixels(); i++) {
      blueIntensity[i] = (sin((millis() / 1000.0) + i * 0.3) + 1) * 127.5;
    }

    for (int i = 0; i < strip.numPixels(); i++) {
      strip.setPixelColor(i, strip.Color(0, 0, blueIntensity[i]));
      strip2.setPixelColor(i, strip.Color(0, 0, blueIntensity[i]));
      strip3.setPixelColor(i, strip.Color(0, 0, blueIntensity[i]));
      strip4.setPixelColor(i, strip.Color(0, 0, blueIntensity[i]));
    }

    strip.show();
    strip2.show();
    strip3.show();
    strip4.show();
    delay(delayTime);

    if(digitalRead(BUTTON) == HIGH){
      mode += 1;
      break;
    }
    if(digitalRead(BUTTON2) == HIGH){
      mode -= 1;
      break;
    }
  }

}

void blueCyanWhiteWave(int delayTime) {
  while (true) {
    for (int i = 0; i < strip.numPixels(); i++) {
      int blueIntensity = (sin((millis() / 1000.0) + i * 0.3) + 1) * 127.5;
      int cyanIntensity = (sin((millis() / 1000.0) + i * 0.3 + 2) + 1) * 127.5;
      int whiteIntensity = (sin((millis() / 1000.0) + i * 0.3 + 4) + 1) * 127.5;

      strip.setPixelColor(i, strip.Color(cyanIntensity, blueIntensity, whiteIntensity)); 
    }
    strip.show();
    delay(delayTime);
  }
}

void blinkingStarlight(int delayTime, int delayTime2, int delayTime3, int delayTime4) {
  while (true) {
    for (int i = 0; i < strip.numPixels(); i++) {
      if (random(5) == 0) {
        strip.setPixelColor(i, strip.Color(255, 255, 255)); 
      } else {
        strip.setPixelColor(i, strip.Color(0, 0, 0)); 
      }
      strip.show();
      delay(delayTime);
    }

    for (int i = 0; i < strip2.numPixels(); i++) {
      if (random(5) == 0) {
        strip2.setPixelColor(i, strip2.Color(255, 255, 255)); 
      } else {
        strip2.setPixelColor(i, strip2.Color(0, 0, 0)); 
      }
      strip2.show();
      delay(delayTime2);
    }

    for (int i = 0; i < strip3.numPixels(); i++) {
      if (random(5) == 0) {
        strip3.setPixelColor(i, strip3.Color(255, 255, 255)); 
      } else {
        strip3.setPixelColor(i, strip3.Color(0, 0, 0)); 
      }
      strip3.show();
      delay(delayTime3);
    }

    for (int i = 0; i < strip4.numPixels(); i++) {
      if (random(5) == 0) {
        strip4.setPixelColor(i, strip4.Color(255, 255, 255)); 
      } else {
        strip4.setPixelColor(i, strip4.Color(0, 0, 0)); 
      }
      strip4.show();
      delay(delayTime4);
    }
  }
}


// void colorRainbow(int wait) {
//   for(long firstPixelHue = 0; firstPixelHue < 5*65536; firstPixelHue += 256) {
//     strip.rainbow(firstPixelHue);
//     strip2.rainbow(firstPixelHue);
//     strip3.rainbow(firstPixelHue);
//     strip4.rainbow(firstPixelHue);
//     strip.show();
//     strip2.show();
//     strip3.show();
//     strip4.show();
//     delay(wait);
//   }
// }

void colorRainbow(int wait) {
  static unsigned long lastUpdate = 0;
  static long firstPixelHue = 0;

  // Only update the LEDs if enough time has passed since the last update
  if (millis() - lastUpdate >= wait) {
    lastUpdate = millis();

    strip.rainbow(firstPixelHue);
    strip2.rainbow(firstPixelHue);
    strip3.rainbow(firstPixelHue);
    strip4.rainbow(firstPixelHue);
    strip.show();
    strip2.show();
    strip3.show();
    strip4.show();

    firstPixelHue += 256;
    if (firstPixelHue >= 5*65536) {
      firstPixelHue = 0;
    }
  }
}


void cyanRain() {

  static int blueledPosition = 0;
  static int whiteledPosition = 1;
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

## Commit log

2023-10-05 Toevoegen 3D ontwerpen button en buttonbox
    [Button Box.stl, Button.stl]
2023-10-09 Toevoegen aangepaste 3D prints
    [Button Box.stl, Button.stl]
2023-11-06 New 3D prints
    [Button Box v2.stl, voeding 3D print v2.stl]
2023-11-08 New version 3D print
    [voeding 3D print v2.stl]
2023-11-20 Button code updated
2023-12-04 Added worked cycling code without threads
2023-12-04 Final electric schematic
2023-12-13 Fixed MQTT issue and code bugs
    [main.cpp]
2023-12-13 Bug fixes in code
    [main.cpp]
